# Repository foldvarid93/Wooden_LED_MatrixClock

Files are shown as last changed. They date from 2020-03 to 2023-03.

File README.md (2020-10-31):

# Wooden LED module matrix clock 

22829030_1608415815887806_506846079193605210_o






2020-10-31_08h34_10

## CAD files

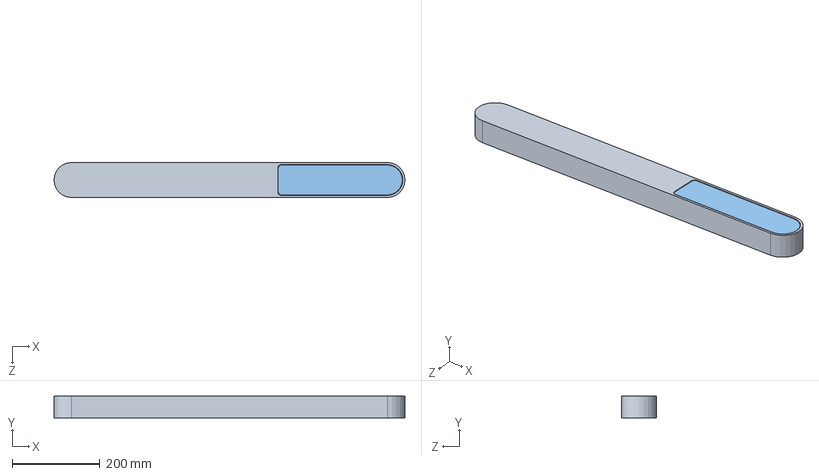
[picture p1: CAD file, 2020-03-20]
04_CAD_CAM/01_CAD/assembly.SLDASM
800.0 x 50.0 x 80.0 mm
flipclock
MAX7219_8X8LED_BOARD x 12

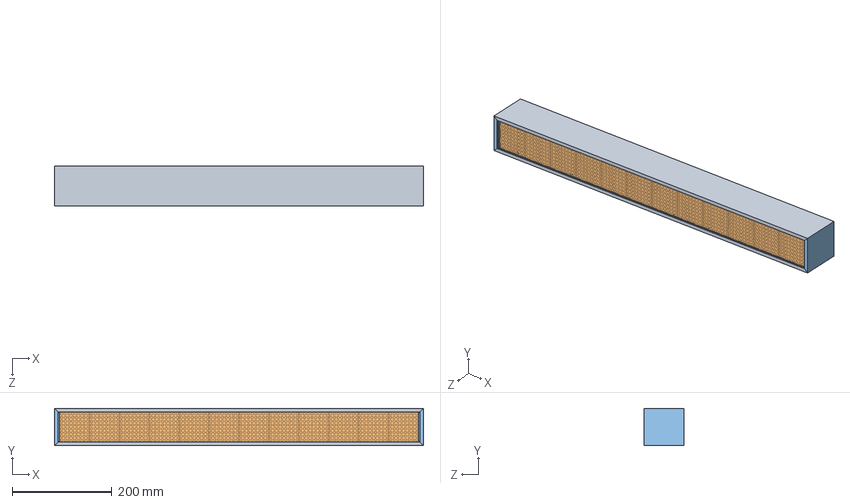
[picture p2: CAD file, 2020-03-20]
04_CAD_CAM/01_CAD/v2/assembly.SLDASM
740.5 x 74.5 x 80.0 mm
hosszu x 2
MAX7219_8X8LED_BOARD x 12
vegek2 x 2

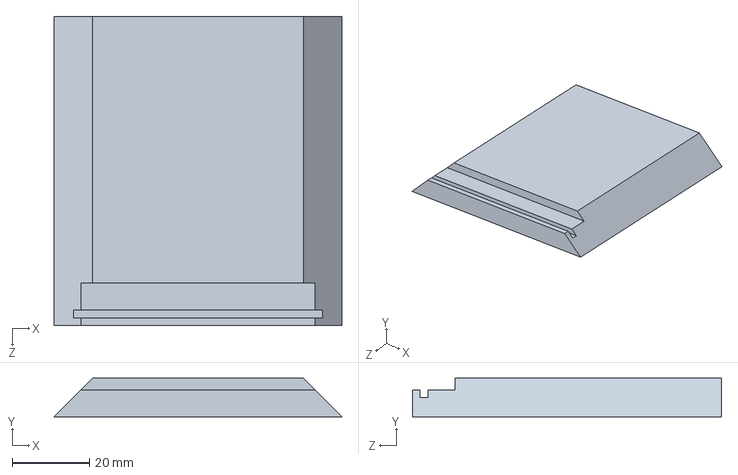
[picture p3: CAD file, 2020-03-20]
04_CAD_CAM/01_CAD/v2/vegek2.SLDPRT
74.5 x 10.0 x 80.0 mm

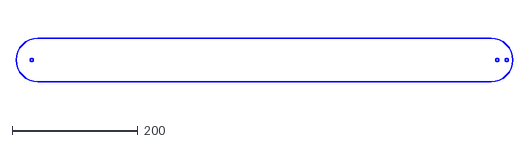
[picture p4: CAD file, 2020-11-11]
04_CAD_CAM/02_CAM/01_Aspire/glass.dxf
789.0 x 69.0

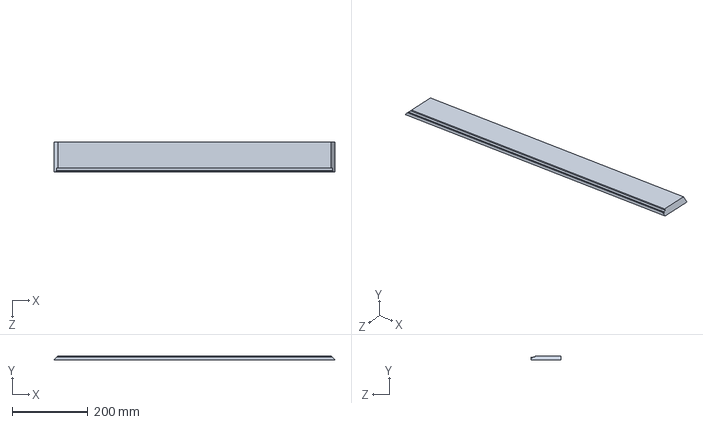
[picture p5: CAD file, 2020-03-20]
04_CAD_CAM/01_CAD/v2/hosszu.SLDPRT
740.5 x 10.0 x 80.0 mm

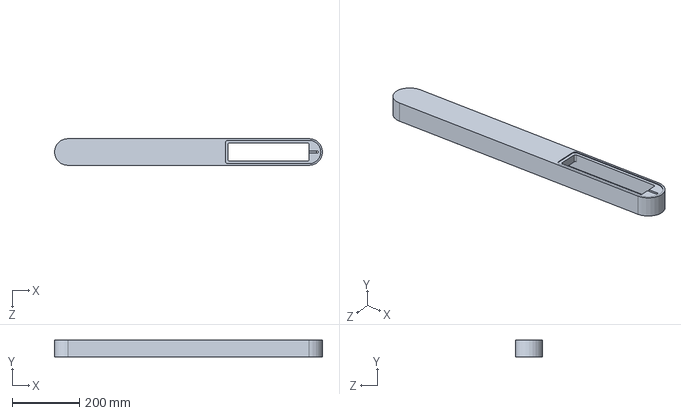
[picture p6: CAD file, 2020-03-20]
04_CAD_CAM/01_CAD/flipclock.SLDPRT
800.0 x 50.0 x 80.0 mm

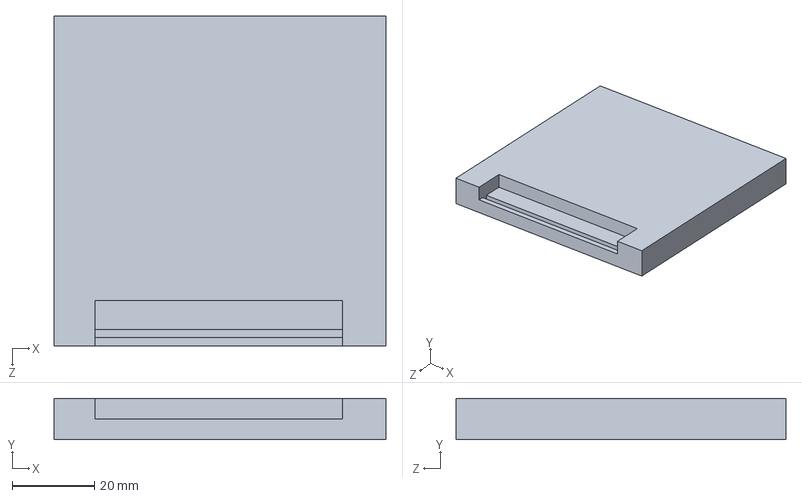
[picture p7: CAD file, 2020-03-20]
04_CAD_CAM/01_CAD/v2/vegek.SLDPRT
80.5 x 10.0 x 80.0 mm

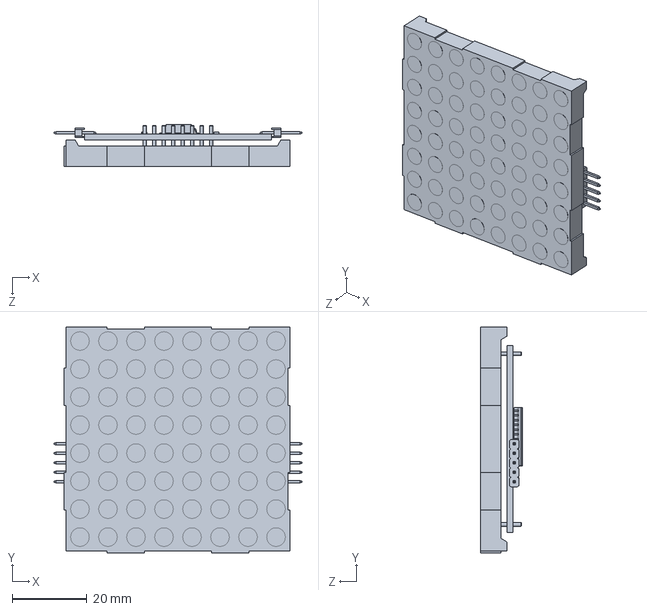
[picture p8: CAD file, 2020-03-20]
04_CAD_CAM/01_CAD/MAX7219_8X8LED_BOARD.SLDPRT
66.4 x 60.5 x 11.3 mm

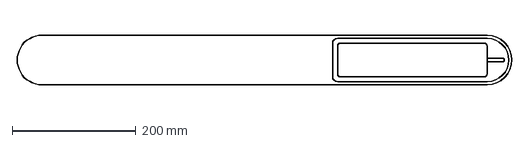
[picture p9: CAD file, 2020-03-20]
04_CAD_CAM/01_CAD/flipclock_b.DXF
801.8 x 80.0 mm

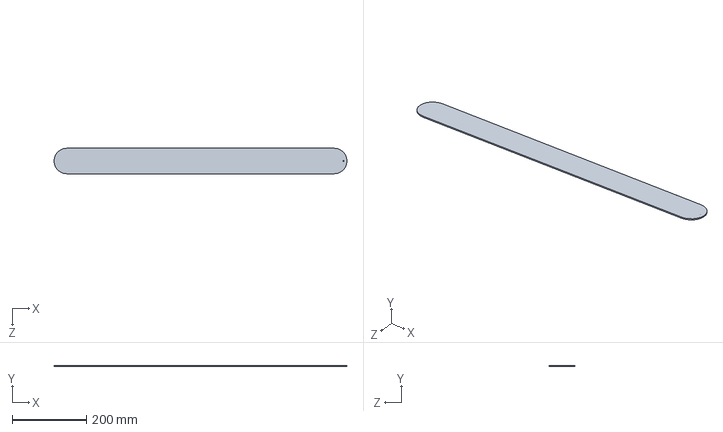
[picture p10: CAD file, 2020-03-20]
04_CAD_CAM/01_CAD/plexi.SLDPRT
789.0 x 3.00 x 69.0 mm

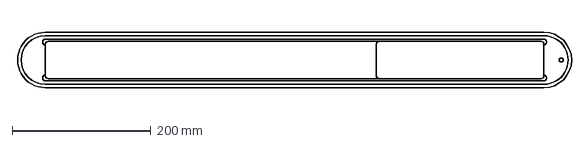
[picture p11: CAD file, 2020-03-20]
04_CAD_CAM/01_CAD/flipclock_f.DXF
801.8 x 80.0 mm

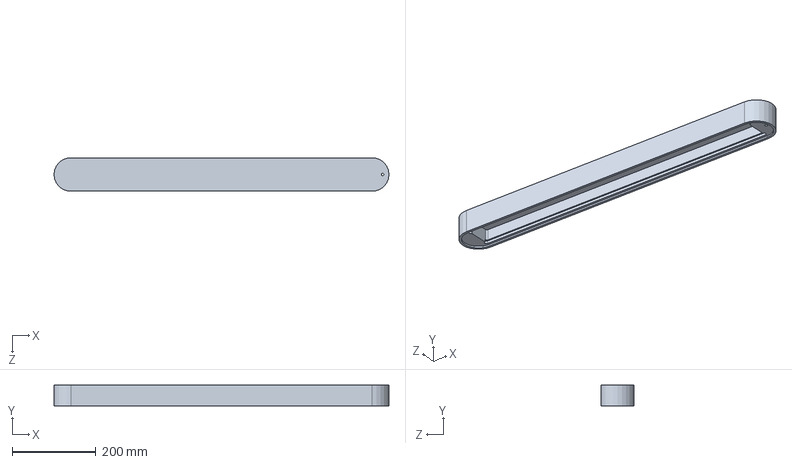
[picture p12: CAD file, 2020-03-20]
04_CAD_CAM/01_CAD/flipclock1.SLDPRT
800.0 x 50.0 x 80.0 mm

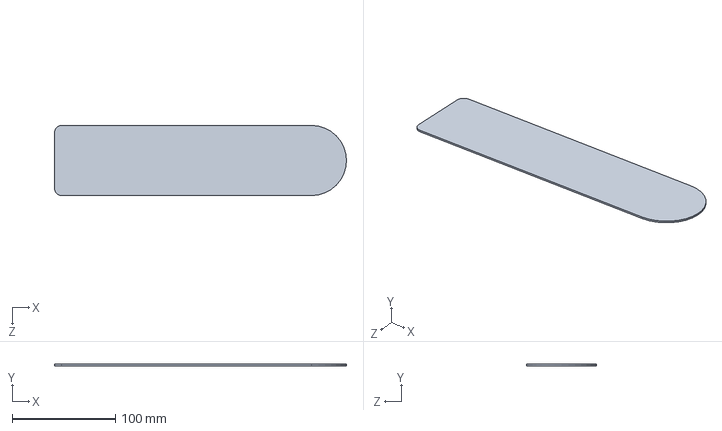
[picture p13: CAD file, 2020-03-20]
04_CAD_CAM/01_CAD/hatsotakaro.SLDPRT
283.0 x 1.50 x 68.0 mm

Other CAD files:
04_CAD_CAM/01_CAD/FlipClockAssembly.SLDASM
04_CAD_CAM/01_CAD/Assem5.SLDASM
04_CAD_CAM/01_CAD/flipclock.DXF
04_CAD_CAM/01_CAD/flipclock.SLDDRW
04_CAD_CAM/02_CAM/01_Aspire/Glass.SLDDRW

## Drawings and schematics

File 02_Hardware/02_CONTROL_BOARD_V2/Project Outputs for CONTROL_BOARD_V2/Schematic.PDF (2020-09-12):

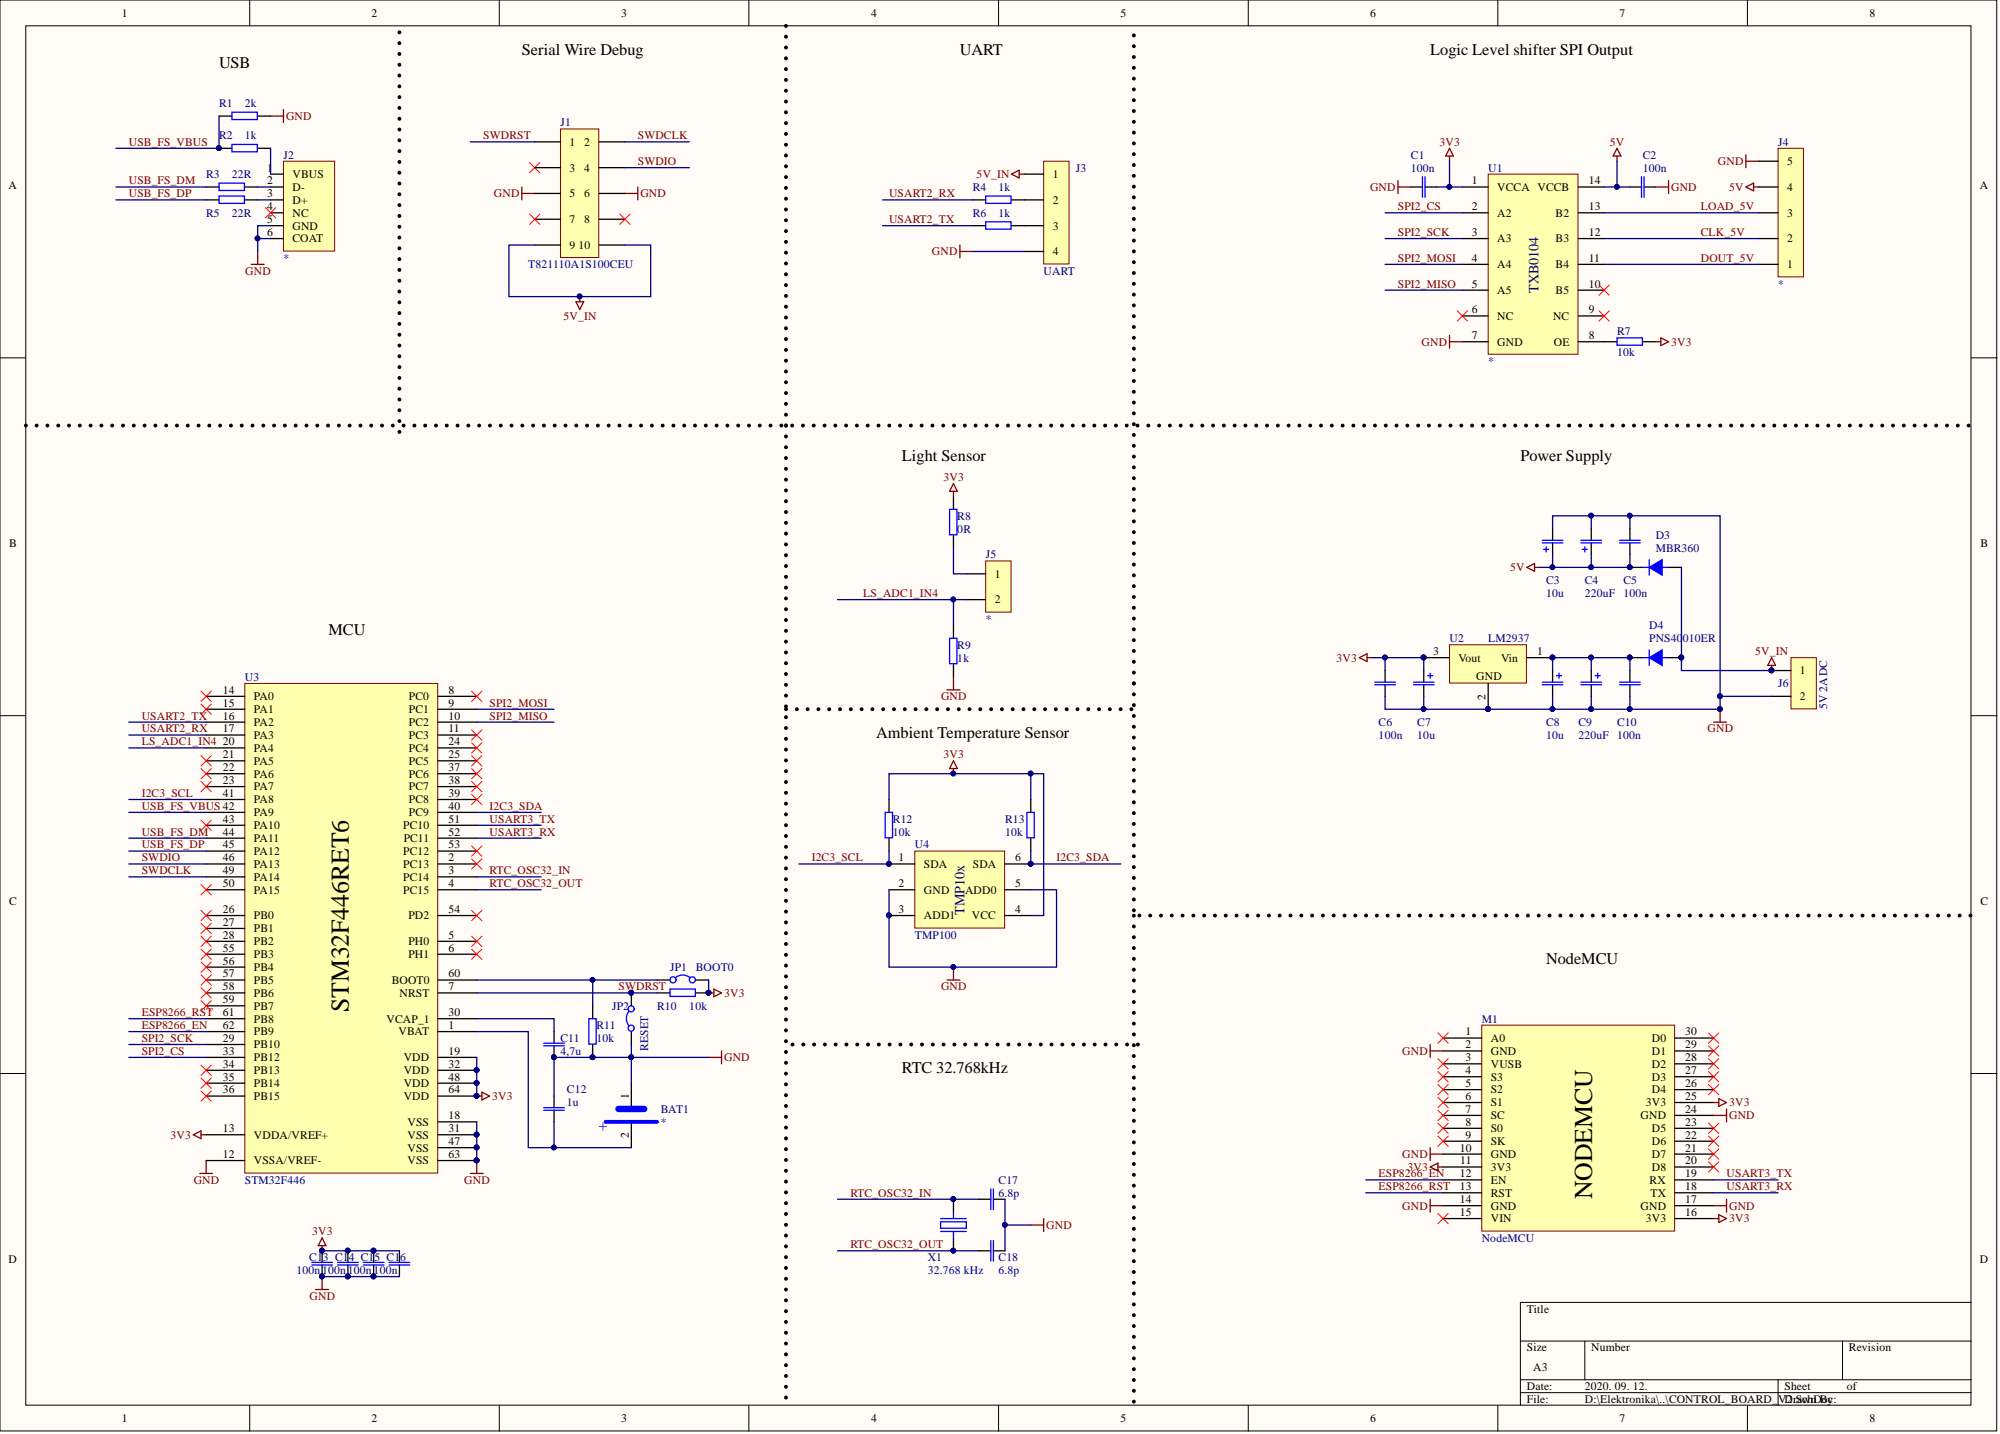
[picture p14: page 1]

Logic Level shifter SPI Output

VDDA/VREF+ 13 | 1u

Designator | Quantity | Name | Value | Description | Distributor | Reference ID | Comment
BAT1 | 1 | | | battery
C1, C2, C5, C6, C10, C | 9 | | 100n | NON POLARIZED CAPACITOR | | | 100n
C3, C7, C8 | 3 | | 10u | POLARIZEDCAPACITOR | | | 10u
C4, C9 | 2 | | 220uF | POLARIZEDCAPACITOR | | | 220uF
C11 | 1 | | 4,7u | NON POLARIZED CAPACITOR | | | 4,7u
C12 | 1 | | 1u | NON POLARIZED CAPACITOR | | | 1u
C17, C18 | 2 | | 6.8p | NON POLARIZED CAPACITOR | | | 6.8p
D3 | 1 | MBR360 | MBR360 | ON SemiconductorMBR360,SCHOTTKY | | | MBR360
D4 | 1 | PNS40010ER | PNS40010ER,115 | Nexperia PNS40010ER,115 switching diode 1.4RS Components | | 136-4874 | PNS40010ER
J1 | 1 | T821 | T821110A1S100CET821, 10pin, 2x5 connector, 2.54mm | | RS Components | 832-3528 | T821110A1S100CEU
J2 | 1 | | | 5PIN miniUSB SMD connector | LOMEX | 43-28-33
J3 | 1 | | UART | 4 PIN HEADER | | | UART
J4 | 1 | | | 5 PIN HEADER
J5 | 1 | | | 2 PIN HEADER
J6 | 1 | 5V 2A DC | 282837-2 | 2 Pin Terminal Block | RS Components | 710-0100 | 5V 2A DC
JP1 | 1 | BOOT0 | | JUMPER | | | BOOT0
JP2 | 1 | RESET | | JUMPER | | | RESET
M1 | 1 | NodeMCU | | Node MCU ESP12 module | | | NodeMCU
R1 | 1 | | 2k | RESISTOR | | | 2k
R2, R4, R6, R9 | 4 | | 1k | RESISTOR | | | 1k
R3, R5 | 2 | | 22R | RESISTOR | | | 22R
R7, R10, R11, R12, R1 | 5 | | 10k | RESISTOR | | | 10k
R8 | 1 | | 0R | RESISTOR | | | 0R
U1 | 1 | | | Voltage level shifter
U2 | 1 | LM2937 | LM2937IMP-3.3/NOLDO-regulator 400mA 3,3 V 5%, 4,75 → 26 V,RSComponents | | | 761-5599 | LM2937
U3 | 1 | STM32F446 | STM32F446RET6 | MCU STM32F446RET6 32bit, ARM Cortex M4, 1RSComp onents | | 110-6621 | STM32F446
U4 | 1 | TMP100 | TMP100 | Temperature sensor with I2C interface | | | TMP100
X1 | 1 | X32K768L104 | 32.768 kHz | Crystal, 32.768 kHz, Cylinder Radial, 8mm x 3mm Farnell | | 9509682 | 32.768 kHz

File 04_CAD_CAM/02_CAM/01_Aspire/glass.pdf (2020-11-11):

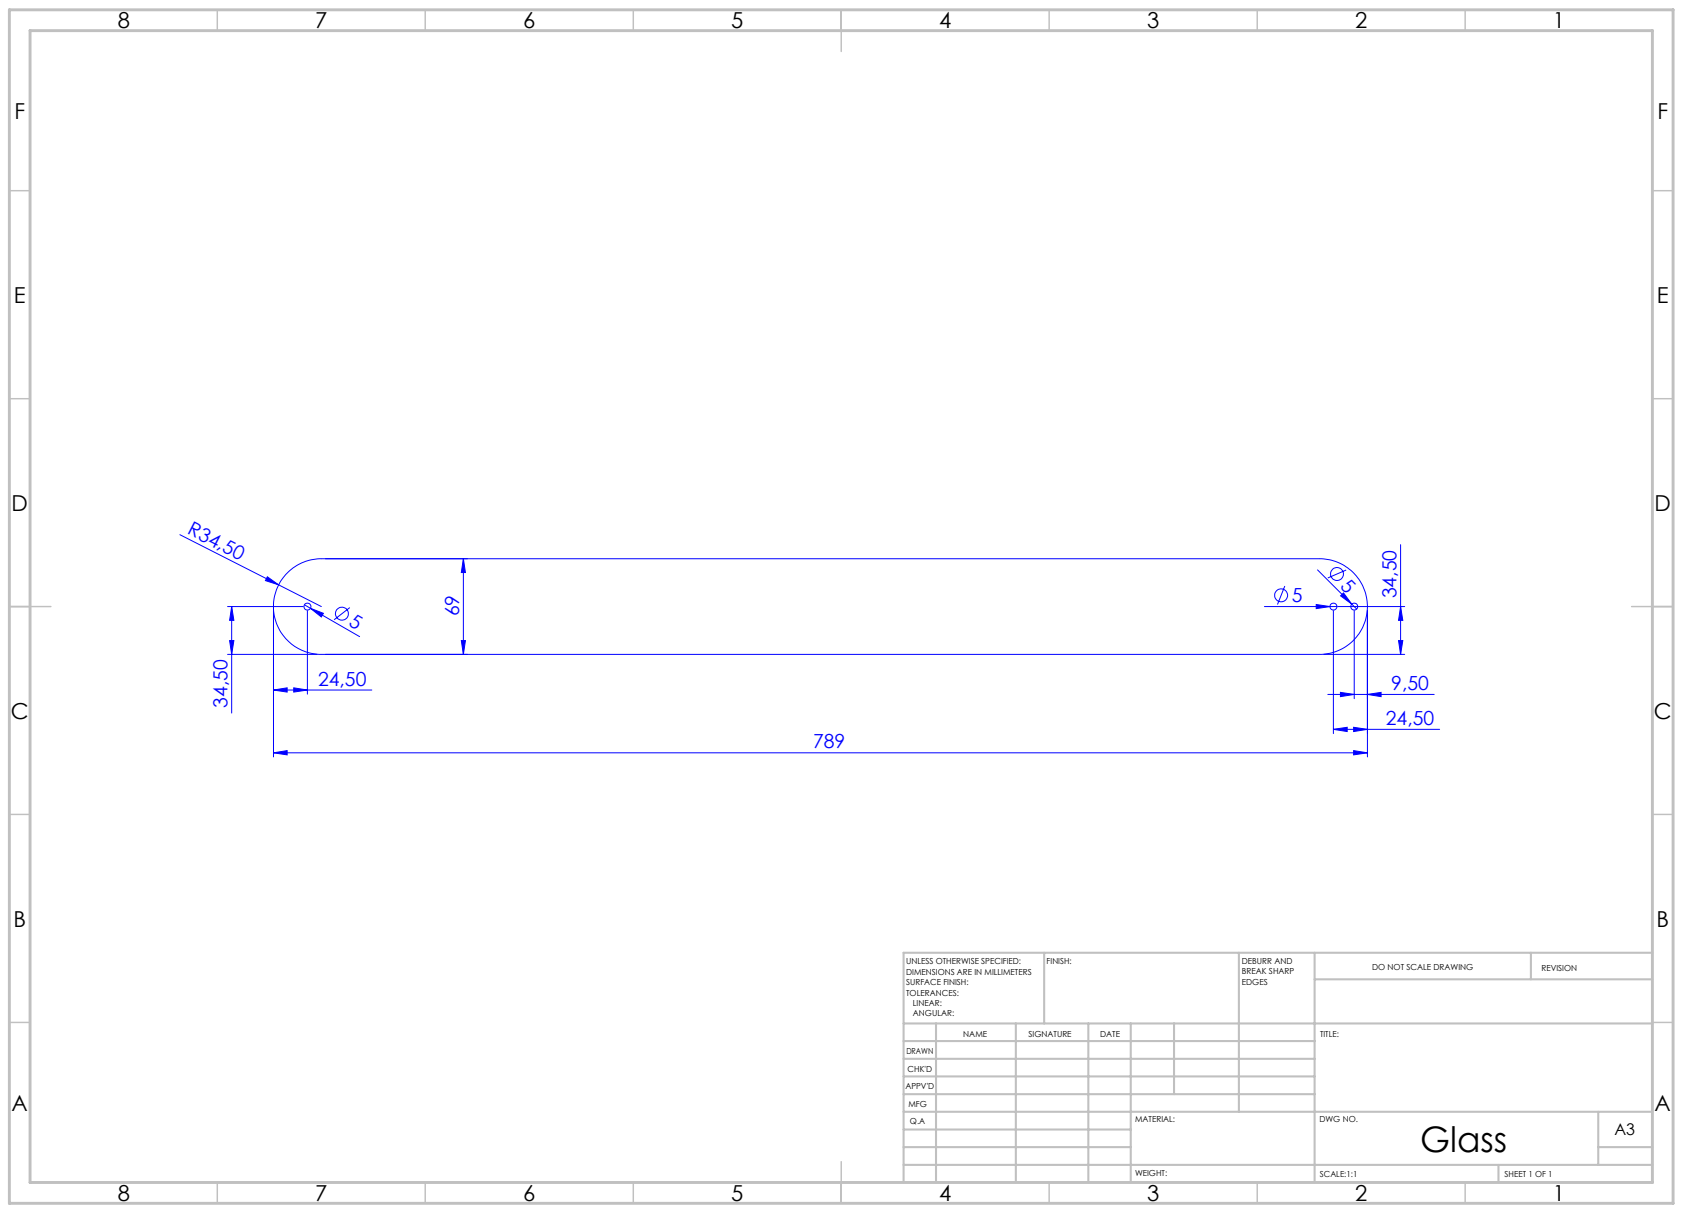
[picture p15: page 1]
FINISH:; DEBURR AND; BREAK SHARP; DO NOT SCALE DRAWING; REVISION; SCALE:1:1; SHEET 1 OF 1

UNLESS OTHERWISE SPECIFIED:
DIMENSIONS ARE IN MILLIMETERS
SURFACE FINISH:
TOLERANCES:
LINEAR:
ANGULAR:

NAME | SIGNATURE | DATE | | | | TITLE:

DRAWN
CHK'D
APPV'D
MFG
Q.A | | | | MATERIAL: | DWG NO. Glass | A3

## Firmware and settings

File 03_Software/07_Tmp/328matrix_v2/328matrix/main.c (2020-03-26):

#define F_CPU 16000000U
#include <util/delay.h>
#include <util/twi.h>
#include <stdlib.h>
#include <stdio.h>
#include <string.h>
#include <avr/interrupt.h>
#include "characters.h"
#include "bitfields.h"
/*********************************///
#pragma GCC diagnostic ignored "-Wchar-subscripts"
#pragma GCC diagnostic ignored "-Wunused-value"
#pragma GCC diagnostic ignored "-Wunused-variable"
/*********************************///
#define		SDAT		portb.bit.b0
#define		SCLK		portb.bit.b1
#define		STROBE		portb.bit.b2
#define		ODAT		portb.bit.b3
#define		OCLK		portb.bit.b4
/*********************************///
//#define		SET			portb.bit.b3
//#define		INCR		portb.bit.b1
//#define		DECR		portb.bit.b2
#define		RTC_ADDR	0xD0
#define		SEC_REG		0x00
/*********************************///
typedef struct RTC_DATA{
	unsigned char	sec;
	unsigned char	min;
	unsigned char	hour;
	unsigned char	day;
	unsigned char	date;
	unsigned char	month;
	unsigned char	year;
}RTC_DATA;
typedef struct TIME{
	unsigned char hour_tens;
	unsigned char hour_singles;
	unsigned char min_tens;
	unsigned char min_singles;
	unsigned char sec_tens;
	unsigned char sec_singles;
}TIME;
typedef struct DATE{
	unsigned char day;
	unsigned char date_tens;
	unsigned char date_singles;
	unsigned char month_tens;
	unsigned char month_singles;
	const char year_thousands;
	const char year_hundreds;
	unsigned char year_tens;
	unsigned char year_singles;
}DATE;
struct {
	unsigned char TIME_SET : 1;
	unsigned char DATE_TIME :1;
} MASK;
struct {
	unsigned char B0 :1;
	unsigned char B1 :1;
	unsigned char B2 :1;
	unsigned char B3 :1;
	unsigned char B4 :1;
	unsigned char B5 :1;
	unsigned char B6 :1;
	unsigned char B7 :1;
} MASKBYTE;
/*********************************///
unsigned char minutes=0;
unsigned char IT=0, PRESS_LENGTH=0,TIMER_LENGTH=0;
unsigned char data[48];
unsigned char datatmp[256];
RTC_DATA	rtcdata;//={0,0,0,6,2,8,15};//sec,min,hour,day,date,month,year
TIME	 	time[2] ={{0,0,0,0,0,0},{0,0,0,0,0,0}};
DATE		date={0,0,0,0,0,2,0,0,0};
const unsigned char	PROGMEM szoveg[] ={"A mai dátum: "};
const unsigned char PROGMEM	weekdays[7][10]={{"hétfõ"},{"kedd"},{"szerda"},{"csütörtök"},{"péntek"},{"szombat"},{"vasárnap"}};
const unsigned char	PROGMEM months[12][12]={{"január"},{"február"},{"március"},{"április"},{"május"},{"június"},{"július"},
{"augusztus"},{"szeptember"},{"október"},{"november"},{"december"}};
/*********************************///
void fill_datatmp(char adat,char kezd){
	for(char i=0;i<6;i++){datatmp[kezd+i]=pgm_read_byte(&(characters[adat][i]));}
}
void copy(char target_from, char target_to, char source_from){
	for(char i=target_from;i<target_to;i++){
		data[i]=datatmp[i+source_from];
	}
}
void fill_display(TIME* time,char kezd){
	fill_datatmp(time->hour_tens+'0',kezd+0);
	fill_datatmp(time->hour_singles+'0',kezd+6);
	fill_datatmp(':',60);	
	fill_datatmp(time->min_tens+'0',kezd+18);
	fill_datatmp(time->min_singles+'0',kezd+24);
	fill_datatmp(':',78);		
	fill_datatmp(time->sec_tens+'0',kezd+36);
	fill_datatmp(time->sec_singles+'0',kezd+42);
}
void shift(const char a){
	STROBE=0;
	for(char i=0;i<6;i++){
		int tmp=data[((5-i)*8)+a];
		for(char j=0;j<8;j++){
			if (tmp &0x80){// 0x01){
				SDAT=0;//SDAT=1;
			}
			else SDAT=1;//SDAT=0
			SCLK=1;
			SCLK=0;
			tmp<<=1;
		}
	}
	for(int i=0;i<6;i++){
		for(char j=8;j>=1;j--){
			if(j==a+1){ODAT=1;}
			else ODAT=0;
			OCLK=1;
			OCLK=0;
		}
	}
	STROBE=1;
}
void clear(char from, char to){
	for(char i=from;i<to;i++){
		data[i]=0xFF;
	}
}
/*********************************///I2C functions
void TWIStart(void){
	TWCR = (1<<TWINT)|(1<<TWSTA)|(1<<TWEN);
	while ((TWCR & (1<<TWINT)) == 0);
}
void TWIStop(void){
	TWCR = (1<<TWINT)|(1<<TWSTO)|(1<<TWEN);
}
void TWIWrite(uint8_t u8data){
	TWDR = u8data;
	TWCR = (1<<TWINT)|(1<<TWEN);
	while ((TWCR & (1<<TWINT)) == 0);
}
char TWIReadACK(void){
	TWCR = (1<<TWINT)|(1<<TWEN)|(1<<TWEA);
	while ((TWCR & (1<<TWINT)) == 0);
	return TWDR;
}
char TWIReadNACK(void){
	TWCR = (1<<TWINT)|(1<<TWEN);
	while ((TWCR & (1<<TWINT)) == 0);
	return TWDR;
}
char TWIGetStatus(void){
	uint8_t status;
	//mask status
	status = TWSR & 0xF8;
	return status;
}
/*********************************///
char atalakit(char tmp){
	char tizes=0;
	while(tmp>=10){
		tizes++;
		tmp-=10;
	}
	tizes<<=4;
	tizes&0x70;
	tmp&=0x0F;
	return(tizes|tmp);
}
void felbont(unsigned char tmp, unsigned char* ten, unsigned char* single){
	*single=(tmp&0x0F);
	tmp>>=4;
	*ten=(tmp&0x07);
}
/*********************************///RTC functions
unsigned char readrtcreg(unsigned char ADDR){
	unsigned char data;
	TWIStart();
	TWIWrite(RTC_ADDR);
	TWIWrite(ADDR);
	TWIStart();
	TWIWrite(RTC_ADDR+0x01);
	data=TWIReadNACK();
	TWIStop();
	return data;
}
void rtcread_time(TIME* time){
/*
	TWIStart();
	TWIWrite(RTC_ADDR);
	TWIWrite(SEC_REG);
	TWIStart();
	TWIWrite(RTC_ADDR+0x01);
	rtcdata.sec=TWIReadACK();
	rtcdata.min=TWIReadACK();
	rtcdata.hour=TWIReadNACK();
	TWIStop();*/
	rtcdata.sec=readrtcreg(0x00);
	rtcdata.min=readrtcreg(0x01);
	rtcdata.hour=readrtcreg(0x02);	
	felbont(rtcdata.hour,&time->hour_tens,&time->hour_singles);
	felbont(rtcdata.min,&time->min_tens,&time->min_singles);
	felbont(rtcdata.sec,&time->sec_tens,&time->sec_singles);
}
void rtcread_date(DATE* date){
/*
	TWIStart();
	TWIWrite(RTC_ADDR);
	TWIWrite(SEC_REG+3);
	TWIStart();
	TWIWrite(RTC_ADDR+0x01);	
	rtcdata.day=TWIReadACK();
	rtcdata.date=TWIReadACK();
	rtcdata.month=TWIReadACK();
	rtcdata.year=TWIReadNACK();
	TWIStop();*/
	rtcdata.day=readrtcreg(0x03);
	rtcdata.date=readrtcreg(0x04);
	rtcdata.month=readrtcreg(0x05);
	rtcdata.year=readrtcreg(0x06);
	date->day=rtcdata.day;
	felbont(rtcdata.date,&date->date_tens,&date->date_singles);
	felbont(rtcdata.month,&date->month_tens,&date->month_singles);
	felbont(rtcdata.year,&date->year_tens,&date->year_singles);	
}
void rtcread(TIME* time, DATE* date){
	rtcread_time(time);
	rtcread_date(date);
}
void rtcwritetime(void){
	TWIStart();
	TWIWrite(RTC_ADDR);
	TWIWrite(SEC_REG);
	TWIWrite(0);
	TWIWrite(atalakit(12));
	TWIWrite(atalakit(9));
	TWIStop();	
}
void rtcwritedate(void){
	TWIStart();
	TWIWrite(RTC_ADDR);
	TWIWrite(SEC_REG+3);
	TWIWrite(2);
	TWIWrite(atalakit(23));
	TWIWrite(atalakit(12));
	TWIWrite(atalakit(15));
	TWIStop();	
}
void first_read(){
	rtcread(&time[1],&date);
	fill_display(&time[1],48);
	copy(0,48,48);
}
/*********************************///Text functions
void text_out(const unsigned char *text){
	unsigned char length=0, temp, i=0,kar_elt=0,b=8;	//length=strlength(text);
	while(text[length]!='\0'){length++;}
	if(length<8){b=length;}
	for(char j=0;j<b;j++){
		temp=text[j];
		for(char k=0;k<6;k++,i++){
			data[i]=pgm_read_byte(&(characters[temp][k]));
		}
	}
	if(length<=8){
		for(;i<48;i++){data[i]=0xff;}
		_delay_ms(3000);
		return;
	}
	for(kar_elt=8;kar_elt<length;kar_elt++){
		temp=text[kar_elt];
		for(char j=0;j<6;j++){
			for(char l=0;l<47;l++){data[l]=data[l+1];}
			data[47]=pgm_read_byte(&(characters[temp][j]));
			_delay_ms(70);
		}
	}
	return;
}
void const_text_out(const unsigned char* text){
	for(unsigned char i=0;pgm_read_byte(&text[i])!='\0'&&i<0xFF;i++){datatmp[i]=pgm_read_byte(&text[i]);}
	text_out(datatmp);
}
/*********************************///Time functions
char concat(char b, char a){
	a>>=1;
	if(b&0x01){a|=0x80;}
	else{a&=0x7F;}
	return a;
}
void time_out(void){
	MASKBYTE.B0=MASKBYTE.B1=MASKBYTE.B2=MASKBYTE.B3=MASKBYTE.B4=MASKBYTE.B5=0;
	rtcread_time(&time[0]);
	fill_display(&time[0],0);	
	
	if (time[0].sec_singles!=time[1].sec_singles) MASKBYTE.B0=1;
	if (time[0].sec_tens!=time[1].sec_tens) MASKBYTE.B1=1;
	if (time[0].min_singles!=time[1].min_singles) MASKBYTE.B2=1;
	if (time[0].min_tens!=time[1].min_tens) MASKBYTE.B3=1;
	if (time[0].hour_singles!=time[1].hour_singles) MASKBYTE.B4=1;
	if (time[0].hour_tens!=time[1].hour_tens) MASKBYTE.B5=1;
	
	if(!MASKBYTE.B0&&!MASKBYTE.B1&&!MASKBYTE.B2&&!MASKBYTE.B3&&!MASKBYTE.B4&&!MASKBYTE.B5){
		//ez helyett vagy kéne 
	}
	else{
		for(int j=0;j<8;j++){
			if(MASKBYTE.B0){for(char i=0;i<6;i++){datatmp[90+i]=concat(datatmp[42+i],datatmp[90+i]);}}
			if(MASKBYTE.B1){for(char i=0;i<6;i++){datatmp[84+i]=concat(datatmp[36+i],datatmp[84+i]);}}
			if(MASKBYTE.B2){for(char i=0;i<6;i++){datatmp[72+i]=concat(datatmp[24+i],datatmp[72+i]);}}
			if(MASKBYTE.B3){for(char i=0;i<6;i++){datatmp[66+i]=concat(datatmp[18+i],datatmp[66+i]);}}
			if(MASKBYTE.B4){for(char i=0;i<6;i++){datatmp[54+i]=concat(datatmp[6+i],datatmp[54+i]);}}
			if(MASKBYTE.B5){for(char i=0;i<6;i++){datatmp[48+i]=concat(datatmp[i],datatmp[48+i]);}}
			for(char i=0;i<48;i++){datatmp[i]>>=1;}
			copy(0,48,48);
			_delay_ms(35);
		}
	}
	time[1]=time[0];
}
void set_time(void){
	time[0].hour_tens=minutes/60;
	time[0].min_tens=minutes%60;
	time[0].hour_singles=(time[0].hour_tens%10)+'0';
	time[0].hour_tens=(time[0].hour_tens/10)+'0';
	time[0].min_singles=(time[0].min_tens%10)+'0';
	time[0].min_tens=(time[0].min_tens/10)+'0';
	
	for(char i=0;i<48;i++){
		if (i==9)i=36;
		datatmp[i]=0xFF;
	}
	fill_datatmp(time[0].hour_tens,9);
	fill_datatmp(time[0].hour_singles,15);
	fill_datatmp(':',21);
	fill_datatmp(time[0].min_tens,27);
	fill_datatmp(time[0].min_singles,33);
	copy(0,48,0);
}
/*********************************///Date functions
void date_out(void){
	unsigned char i=0;
	rtcread_date(&date);
	for(i=0;i<8;i++){datatmp[i]=' ';}
	for(unsigned char j=0;pgm_read_byte(&szoveg[j])!='\0';i++,j++){datatmp[i]=pgm_read_byte(&szoveg[j]);}
	datatmp[i++]=date.year_thousands+'0';
	datatmp[i++]=date.year_hundreds+'0';
	datatmp[i++]=date.year_tens+'0';
	datatmp[i++]=date.year_singles+'0';
	datatmp[i++]='.';
	datatmp[i++]=date.month_tens+'0';
	datatmp[i++]=date.month_singles+'0';
	datatmp[i++]='.';
	datatmp[i++]=date.date_tens+'0';
	datatmp[i++]=date.date_singles+'0';
	datatmp[i++]='.';
	for(char j=0;pgm_read_byte(&weekdays[date.day][j])!='\0';i++,j++){
		datatmp[i]=pgm_read_byte(&weekdays[date.day][j]);
	}
	for(char j=0;j<8;i++,j++){datatmp[i]=' ';}
	datatmp[i]='\0';
	text_out(datatmp);
}
/*********************************///
void TWIInit(void){	//set SCL to 400kHz
	TWSR = 0x00;
	TWBR = 0x0C;
	TWCR = (1<<TWEN);	//enable TWI
}
void init_avr(void){
	DDRB=0xFF;
	DDRC=0xFF;
	DDRD=0b11111011;	//DDRD &= ~(1 << DDD2);     // Clear the PD2 pin	// PD2 (PCINT0 pin) is now an input
	PORTD |= (1 << PORTD2);    // turn On the Pull-up	// PD2 is now an input with pull-up enabled
	EICRA |= (1 << ISC01);    // set INT0 to trigger on ANY logic change
	EIMSK |= (1 << INT0);     // Turns on INT0
}	
void Init_Timer0(void){
	TCCR0A|=0B00000010;//setWGM01
	TCCR0A&=0B11111110;//clearWGM00
	TCCR0B|=0B00000011;//setCS01
	TCCR0B&=0B11110011;//clearWGM02, clearCS00, clear CS02		
	TIMSK0 |= (1 << TOIE0);
	OCR0A=0xFF;
}
void Init_Timer1(void){
    OCR1A = 15624;
    TCCR1B |= (1 << WGM12);
    TIMSK1 |= (1 << OCIE1A);
    TCCR1B |= (1 << CS12) | (1 << CS10);
}
/*********************************///
void main(void){
	init_avr();	
	Init_Timer0();
	sei();
	TWIInit();
	//TWIStart();
	//TWIWrite(RTC_ADDR);
	//TWIWrite(SEC_REG+7);
	//TWIWrite(0x10);
	//TWIStop();	
	//rtcwritetime();
	//rtcwritedate();
	first_read();
    while (1){
		//const_text_out(szoveg);
		//date_out();
		time_out();
		_delay_ms(25);
	}
}
/*********************************///
ISR (TIMER0_OVF_vect){
	if (IT==8){	IT=0;}
	shift(IT);
	IT++;
}
ISR (TIMER1_COMPA_vect){
	///spi kiszolgálás 
}
ISR (INT0_vect){
	portb.bit.b5=~portb.bit.b5;
}
/*********************************///
//void interrupt TIMER_ISR(void) {
	//if (PIR1bits.TMR1IF==1){
		//if(SET&&!MASK.TIME_SET){
			//TIMER_LENGTH++;
			//if(TIMER_LENGTH==100){
				//MASK.DATE_TIME=1;
				//TIMER_LENGTH=0;
			//}
		//}
		//if(!SET&&!MASK.TIME_SET){
			//MASK.TIME_SET=1;
			//TIMER_LENGTH=50;
			//rtcread(&time[0],&date);
			//minutes=time[0].min_singles+time[0].min_tens*10+((time[0].hour_singles+time[0].hour_tens*10)*60);
		//}
		//if(TIMER_LENGTH>0&&MASK.TIME_SET){
			//if (INCR == 1 & DECR == 1) {
				//PRESS_LENGTH = 0;
				//TIMER_LENGTH--;
				//if(TIMER_LENGTH==0){
					//MASK.TIME_SET=0;
					//rtcwrite_time(minutes);
				//}
			//}
			////----------------------------------------------------------------------------////NÖVELÉS
			//if (INCR == 0) {
				//if (PRESS_LENGTH <= 10) {minutes++;PRESS_LENGTH++;}
				//if (PRESS_LENGTH<30&&PRESS_LENGTH>10) {minutes += 10;PRESS_LENGTH++;}
				//if (PRESS_LENGTH >= 30) {minutes += 60;}
				//if (minutes>1439){minutes-=1440;}
			//}
			////----------------------------------------------------------------------------////CSÖKKENTÉS
			//if (DECR == 0) {
				//if (PRESS_LENGTH <= 10) {minutes--;PRESS_LENGTH++;}
				//if (PRESS_LENGTH > 10&&PRESS_LENGTH<30) {minutes-=10;PRESS_LENGTH++;}
				//if (PRESS_LENGTH >= 30) {minutes -= 60;}
				//if (minutes<0){minutes+=1440;}
			//}
		//}
		//TMR1L=0x00;
		//TMR1H=0x00;
		//PIR1bits.TMR1IF=0;
	//}
//}
		//for(char j=0;j<9;j++){
			//temp=pgm_read_byte(&(text[j]));	
			//for(char k=0;k<6;k++){
				//data[i]=pgm_read_byte(&(characters[temp][k]));		//			data[i]=characters[((*(text+j))*6)+k];
				//i++;
			//}						
		//}
		//
		//
		//while(1){
			//i=0;
			//if((length-kar_elt)==8){break;}//vége 
			//if(betu_elt!=0){
				//i=0;
				//temp=pgm_read_byte(&(text[kar_elt]));
				//for(char j=0;j<(6-betu_elt);j++,i++){
					//data[i]=pgm_read_byte(&(characters[temp][j]));
				//}
			//}
			//b=kar_elt;
			//if(betu_elt!=0){
				//b++;
			//}
			//while(i<48){
				//for(char j=0;j<6;j++,i++){
					//data[i]=pgm_read_byte(&(characters[(text+b)][j]));
				//}
				//b++;
			//}
			//betu_elt++;
			//if(betu_elt==6){
				//betu_elt=0;
				//kar_elt++;
			//}
			//_delay_ms(15);
		//}
	//}
		//for(;kar_elt+8<=length;kar_elt++){
		//i=0;
		//for(char j=0;j<8;j++){
			//temp=pgm_read_byte(&(text[kar_elt+j]));
			//for(char k=0;k<6;k++,i++){
				//data[i]=pgm_read_byte(&(characters[temp][k]));
			//}
		//}
	//}
		//if(length<9){
		//for(char j=0;j<length;j++){
			//temp=pgm_read_byte(&(text[j]));			
			//for(char k=0;k<6;k++,i++){
				//data[i]=pgm_read_byte(&(characters[temp][k]));		//			data[i]=characters[((*(text+j))*6)+k];
			//}
		//}
		//for(;i<48;i++){
			//data[i]=0xff;
		//}
		//_delay_ms(3000);
	//}
	//void text_out(const unsigned char* text){
		//unsigned char length, temp;
		//length=strlength(text);
		//for(char j=0; j<length;j++){
			//temp=pgm_read_byte(&(text[j]));
			//for(char i=0;i<6;i++){
				//data[(j*6)+i]=pgm_read_byte(&(characters[temp][i]));
			//}
		//}
	//}
//char strlength(const unsigned char* text){
	//unsigned char length=0;
	//while(pgm_read_byte(&text[length])!='\0'){
		//length++;
	//}
	//return length;
//}	
/**************************************************///inicializálások

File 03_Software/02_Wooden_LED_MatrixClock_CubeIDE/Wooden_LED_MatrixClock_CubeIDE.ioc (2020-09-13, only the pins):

Mcu.UserName=STM32F446RETx
PA13.GPIO_Label=SWDIO
PA13.Signal=SYS_JTMS-SWDIO
PA14.GPIO_Label=SWDCLK
PA14.Signal=SYS_JTCK-SWCLK
PA2.GPIO_Label=USART2_TX
PA2.Signal=USART2_TX
PA3.GPIO_Label=USART2_RX
PA3.Signal=USART2_RX
PA4.GPIO_Label=LS_ADC1_IN4
PA4.Signal=ADCx_IN4
PA8.Signal=I2C3_SCL
PB10.Signal=SPI2_SCK
PB12.GPIO_Label=SPI2_CS
PB12.Signal=GPIO_Output
PB8.GPIO_Label=ESP8266_RST
PB8.Signal=GPIO_Output
PB9.GPIO_Label=ESP8266_EN
PB9.Signal=GPIO_Output
PC1.Signal=SPI2_MOSI
PC10.Signal=USART3_TX
PC11.Signal=USART3_RX
PC14-OSC32_IN.Signal=RCC_OSC32_IN
PC15-OSC32_OUT.Signal=RCC_OSC32_OUT
PC2.Signal=SPI2_MISO
PC9.Signal=I2C3_SDA
PH0-OSC_IN.Signal=RCC_OSC_IN
PH1-OSC_OUT.Signal=RCC_OSC_OUT

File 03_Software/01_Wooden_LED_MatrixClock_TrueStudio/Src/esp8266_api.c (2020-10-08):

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

/* Includes ------------------------------------------------------------------*/
#include "main.h"
#include "string.h"
#include "stdlib.h"

UART_HandleTypeDef huart1;
UART_HandleTypeDef huart2;

/* USER CODE BEGIN PV */
#define DEBUG 1
#define AT_COMMAND_BUFFER_LENGTH 255
#define UART_RECEIVE_BUFFER_LENGTH 2048

uint8_t uartRxByte[1];
uint16_t i=0,j=0;
uint8_t *ptr;
uint8_t  c;
uint8_t AT_command[AT_COMMAND_BUFFER_LENGTH];
uint8_t uartReceive[UART_RECEIVE_BUFFER_LENGTH];
uint8_t uartReceiveEnd=0;
uint8_t HTTP_response[]="HTTP/1.1 200 OK\r\nContent-Type: text/html\r\nConnection: Closed\r\n\r\n\r\n";
HAL_StatusTypeDef res;
uint8_t handleData=0;
uint8_t HTTP_request_length_string[10];
uint16_t HTTP_request_length=0;
uint8_t HTTP_request_length_valid=0;

extern uint8_t webpage[1271];


/* USER CODE END PV */

void SystemClock_Config(void);
static void MX_GPIO_Init(void);
static void MX_USART1_UART_Init(void);
static void MX_USART2_UART_Init(void);
/**
  * @brief  The application entry point.
  * @retval int
  */
int main(void)
{
  /* USER CODE BEGIN 1 */
	InitWebpage();


  /* USER CODE END 1 */

  /* MCU Configuration--------------------------------------------------------*/

  /* Reset of all peripherals, Initializes the Flash interface and the Systick. */
  HAL_Init();

  /* Configure the system clock */
  SystemClock_Config();

  /* Initialize all configured peripherals */
  MX_GPIO_Init();
  MX_USART1_UART_Init();
  MX_USART2_UART_Init();
  /* USER CODE BEGIN 2 */
  	//HAL_UART_Receive_IT(&huart1, uartRxByte, 1);
	#ifdef DEBUG
		debugPrintf("\r\n");
		debugPrintf("\r\n");
		debugPrintf("######################\r\n");
		debugPrintf("######################\r\n");
		debugPrintf("######################\r\n");
	#endif

	//restore
	/*sprintf(AT_command,"%s","AT+RESTORE\r\n");
	HAL_UART_Transmit(&huart1,AT_command,strlen(AT_command),100);
	HAL_UART_Receive(&huart1,uartReceive,1024,100);
	//waitForUartResponse();
	//uartReceiveEnd=0;
	debugPrintf("ESP8266 restored to default\r\n");
	//debugPrintf(uartReceive);
	debugPrintf("-------------\r\n");*/

	//set uart parameters
	/*sprintf(AT_command,"%s","AT+UART_CUR=115200,8,1,0,0\r\n");
	HAL_UART_Transmit(&huart1,AT_command,strlen(AT_command),100);
	HAL_UART_Receive(&huart1,uartReceive,1024,100);
	//waitForUartResponse();
	//uartReceiveEnd=0;
	debugPrintf("ESP8266 uart parameters set\r\n");
	//debugPrintf(uartReceive);
	debugPrintf("-------------\r\n");*/

	//HAL_Delay(5000);

	//ATE0 switch off echo
	sprintf(AT_command,"%s","ATE0\r\n");
	HAL_UART_Transmit(&huart1,AT_command,strlen(AT_command),100);
	HAL_UART_Receive(&huart1,uartReceive,UART_RECEIVE_BUFFER_LENGTH,100);
	#ifdef DEBUG
		debugPrintf("ESP8266 echo switched off\r\n");
		//debugPrintf(uartReceive);
		debugPrintf("-------------\r\n");
	#endif


	//set wifi mode to Station mode (to be able to connect to a wifi router )
	sprintf(AT_command,"%s","AT+CWMODE_CUR=1\r\n");
	HAL_UART_Transmit(&huart1,AT_command,strlen(AT_command),100);
	HAL_UART_Receive(&huart1,uartReceive,UART_RECEIVE_BUFFER_LENGTH,100);
	#ifdef DEBUG
		debugPrintf("wifi mode set to Station mode: ");
		debugPrintf(uartReceive);
		debugPrintf("-------------\r\n");
	#endif

	//connect to a wifi network
	sprintf(AT_command,"%s%c%s%c%c%c%s%c%s","AT+CWJAP_CUR=",'"',"WIFI_network_name",'"',',','"',"WIFI_password",'"',"\r\n");  //replace WIFI_network_name and WIFI_password with your wifi network name and your password
	HAL_UART_Transmit(&huart1,AT_command,strlen(AT_command),100);
	debugPrintf("connecting to network...\r\n");
	HAL_UART_Receive(&huart1,uartReceive,UART_RECEIVE_BUFFER_LENGTH,10000); //give 10 seconds to connect to the wifi router
	#ifdef DEBUG
		debugPrintf(uartReceive);
		debugPrintf("-------------\r\n");
	#endif

	//get the mac address of ESP8266
	/*sprintf(AT_command,"%s","AT+CIPSTAMAC_CUR?\r\n");
	HAL_UART_Transmit(&huart1,AT_command,strlen(AT_command),100);
	HAL_UART_Receive(&huart1,uartReceive,255,100);
	debugPrintf("ESP8266 mac address: ");
	debugPrintf(uartReceive);
	debugPrintf("-------------\r\n");*/

	//get ip address of ESP8266
	sprintf(AT_command,"%s","AT+CIFSR\r\n");
	HAL_UART_Transmit(&huart1,AT_command,strlen(AT_command),100);
	HAL_UART_Receive(&huart1,uartReceive,UART_RECEIVE_BUFFER_LENGTH,100);
	#ifdef DEBUG
		debugPrintf("ESP8266 ip address: ");
		debugPrintf(uartReceive);
		debugPrintf("-------------\r\n");
	#endif

	//enable multiple connections
	sprintf(AT_command,"%s","AT+CIPMUX=1\r\n");
	HAL_UART_Transmit(&huart1,AT_command,strlen(AT_command),100);
	HAL_UART_Receive(&huart1,uartReceive,UART_RECEIVE_BUFFER_LENGTH,100);
	#ifdef DEBUG
		debugPrintf("single connection enabled: ");
		debugPrintf(uartReceive);
		debugPrintf("-------------\r\n");
	#endif

	//create server on port 80
	sprintf(AT_command,"%s","AT+CIPSERVER=1,80\r\n");
	HAL_UART_Transmit(&huart1,AT_command,strlen(AT_command),100);
	HAL_UART_Receive(&huart1,uartReceive,UART_RECEIVE_BUFFER_LENGTH,100);
	#ifdef DEBUG
		debugPrintf("Server started on port 80: ");
		debugPrintf(uartReceive);
		debugPrintf("-------------\r\n");
	#endif

	//start listening for HTTP requests
	HAL_UART_Receive_IT(&huart1, uartRxByte, 1);
  /* USER CODE END 2 */

  /* Infinite loop */
  /* USER CODE BEGIN WHILE */
  while (1)
  {
    /* USER CODE END WHILE */

    /* USER CODE BEGIN 3 */
	  /*HAL_GPIO_TogglePin(GPIOA,GPIO_PIN_5);
	  HAL_Delay(200);*/

	  if (handleData==1){
		  debugPrintf(uartReceive);
		  debugPrintf("\r\n");
		  debugPrintf("\r\nhandling received data\r\n");
		  HandleReceivedData();
		  handleData=0;
		  HAL_UART_Receive_IT(&huart1, uartRxByte, 1);
	  }

	 // HAL_Delay(100);
  }
  /* USER CODE END 3 */
}

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
/* USER CODE BEGIN 4 */

void HAL_UART_RxCpltCallback(UART_HandleTypeDef *UartHandle)
{
  /* Set transmission flag: transfer complete */
  //UartReady = SET;
	//HAL_GPIO_WritePin(LD2_GPIO_Port, LD2_Pin, GPIO_PIN_SET);


//	 -------------------------------------------------
//	 	 If the esp8266 gets a reuest on port 80 it will send the incoming TCP data to the microcontorller with a header:
//		example:
//
//		+IPD,0,321:GET / HTTP/1.1
//		Host: 192.168.1.104
//		User-Agent: Mozilla/5.0 (X11; Ubuntu; Linux x86_64; rv:66.0) Gecko/20100101 Firefox/66.0
//		Accept: text/html,application/xhtml+xml,application/xml;q=0.9,*/*;q=0.8
//		Accept-Language: en-US,en;q=0.5
//		Accept-Encoding: gzip, deflate
//		Connection: keep-alive
//		Upgrade-I..........
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

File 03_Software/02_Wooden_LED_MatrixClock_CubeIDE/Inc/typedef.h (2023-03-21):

/*
 * typedeff.h
 *
 *  Created on: 2020. okt. 21.
 *      Author: David
 */

#ifndef TYPEDEF_H_
#define TYPEDEF_H_
/**** INCLUDES ***********************************************************************************/
#include <stdbool.h>
#include <stdint.h>
/**** END OF INCLUDES ****************************************************************************/

/**** MACROS *************************************************************************************/
#define VA_NTP_SSID							(0x0)
#define SO_NTP_SSID							(50u)
	/**/
#define VA_NTP_PassWord 					(VA_NTP_SSID + SO_NTP_SSID)
#define SO_NTP_PassWord						(50u)
	/**/
#define VA_NTP_SyncEnabled 					(VA_NTP_PassWord + SO_NTP_PassWord)
#define SO_NTP_SyncEnabled					(2u)
	/**/
#define VA_NTP_SyncInterval 				(VA_NTP_SyncEnabled + SO_NTP_SyncEnabled)
#define SO_NTP_SyncInterval					(2u)
	/*Text*/
#define VA_Text_Message						(VA_NTP_SyncInterval + SO_NTP_SyncInterval)
#define SO_Text_Message						(256u)
	/**/
#define VA_Text_Enabled						(VA_Text_Message + SO_Text_Message)
#define SO_Text_Enabled						(2u)
	/**/
#define VA_Text_ScrollingMode				(VA_Text_Enabled + SO_Text_Enabled)
#define SO_Text_ScrollingMode				(2u)
	/**/
#define VA_Text_ScrollIntervalInSec			(VA_Text_ScrollingMode + SO_Text_ScrollingMode)
#define SO_Text_ScrollIntervalInSec			(2u)
	/*Date*/
#define VA_Date_Enabled						(VA_Text_ScrollIntervalInSec + SO_Text_ScrollIntervalInSec)
#define SO_Date_Enabled						(2u)
	/**/
#define VA_Date_ScrollingMode				(VA_Date_Enabled + SO_Date_Enabled)
#define SO_Date_ScrollingMode				(2u)
	/**/
#define VA_Date_ScrollIntervalInSec			(VA_Date_ScrollingMode + SO_Date_ScrollingMode)
#define SO_Date_ScrollIntervalInSec			(2u)
	/*Temp*/
#define VA_Temp_Enabled						(VA_Date_ScrollIntervalInSec + SO_Date_ScrollIntervalInSec)
#define SO_Temp_Enabled						(2u)
	/**/
#define VA_Temp_ScrollingMode				(VA_Temp_Enabled + SO_Temp_Enabled)
#define SO_Temp_ScrollingMode				(2u)
	/**/
#define VA_Temp_ScrollIntervalInSec			(VA_Temp_ScrollingMode + SO_Temp_ScrollingMode)
#define SO_Temp_ScrollIntervalInSec			(2u)
	/*Others*/
#define VA_TimeAnimation					(VA_Temp_ScrollIntervalInSec + SO_Temp_ScrollIntervalInSec)
#define SO_TimeAnimation					(2u)
	/**/
#define VA_DisplayBrightnessMode			(VA_TimeAnimation + SO_TimeAnimation)
#define SO_DisplayBrightnessMode			(2u)
	/**/
#define VA_DisplayBrightness				(VA_DisplayBrightnessMode + SO_DisplayBrightnessMode)
#define SO_DisplayBrightness				(2u)
	/**/
#define SizeOf_CharacterOnDisplay			(0x0006)
#define SizeOf_DisplayTextColumnArray		((SizeOf_CharacterOnDisplay * SO_Text_Message)+(2*NumberOf_DisplayColumn))
#define SizeOf_WhiteSpaces					(NumberOf_DisplayColumn/SizeOf_CharacterOnDisplay)
#define NumberOf_ColumnOfOneDisplay			(8)
#define NumberOf_Display					(12)
#define NumberOf_DisplayColumn				(NumberOf_Display * NumberOf_ColumnOfOneDisplay)
/**** END OF MACROS ******************************************************************************/

/**** TYPE DEFINITIONS ***************************************************************************/
enum
{
	SM_JustText = 0,
	SM_ScrollInAndOut
};

/*AppState_t*/
typedef enum
{
	AS_None = 0u,
	AS_Time,
	AS_Date,
	AS_Text,
	AS_Temp,
	AS_TextDone,
	AS_TextRunning
}AppState_t;
#define AppState_t uint8_t

/*AppState_t*/
typedef enum
{
	WiFi_None = 0,
	WiFi_NTP,
	WiFi_AP
}WiFiState_t;
#define WiFiState_t uint8_t

/*TextMode_t*/
typedef enum
{
	TM_MessageNoScroll = 0,
	TM_MessageScroll,
	TM_MessageScrollInAndOut
}TextMode_t;
#define TextMode_t uint16_t

/*DateMode_t*/
typedef enum
{
	DM_DateNoScroll = 0,
	DM_DateScrollInAndOut,
	DM_DateMessageScroll,
	DM_DateMessageScrollInAndOut
}DateMode_t;
#define DateMode_t uint16_t

typedef enum
{
	DB_Automatic = 0,
	DB_Manual
}DispBrightness_t;
#define DispBrightness_t uint16_t
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

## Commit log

2020-03-20 sorting files
    [Assem5.SLDASM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]
2020-03-20 reordering files
    [Assem5.SLDASM, FlipClockAssembly.SLDASM, MAX7219_8X8LED_BOARD.SLDPRT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]
2020-03-21 reordering sw project file structure
    [GPIOTEST Debug.cfg]
2020-03-22 Working SW with 96 column STM32L476RG nucleo Signed-off-by: foldvarid93 <foldvarid93@gmail.com>
2020-06-04 library alignment
    [CONTROL_BOARD.PrjPcb]
2020-08-08 ControlBoardV2 initial commit
    [CONTROL_BOARD_V2.PrjPcb, CONTROL_BOARD_V2.SchDoc]
2020-08-16 NodeMCU added to schematic
    [CONTROL_BOARD_V2.PrjPcb, CONTROL_BOARD_V2.SchDoc]
2020-08-17 Continue with schematic design
    [CONTROL_BOARD_V2.SchDoc, MAX7219_8X8LED_BOARD.PrjPcb]
2020-08-21 Pcb design first commit
    [CONTROL_BOARD_V2.PrjPcb, CONTROL_BOARD_V2.SchDoc, flipclock.DXF]
2020-08-22 Control board design finished
    [CONTROL_BOARD_V2.PrjPcb, CONTROL_BOARD_V2.SchDoc]
2020-08-23 PCB design done
    [CONTROL_BOARD_V2.PrjPcb, CONTROL_BOARD_V2.SchDoc]
2020-08-23 Fabrication Output files generated
    [CONTROL_BOARD_V2.SchDoc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]
2020-08-23 LED Matrix PCB redesign
    [MAX7219_8X8LED_BOARD.PcbDoc, MAX7219_8X8LED_BOARD.PrjPcb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]
2020-08-24 HW folder refactor
    [CONTROL_BOARD.PcbDoc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]
2020-09-06 RemoteXY develope
    [Assem5.SLDASM, FlipClockAssembly.SLDASM, MAX7219_8X8LED_BOARD.SLDPRT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]
2020-09-12 New truestudio sw project create
    [CONTROL_BOARD_V2.PrjPcb]
2020-09-14 RTC LSE in use Vbat RTC is working
    [CONTROL_BOARD_V2.PrjPcb]
2020-09-14 Interrupt priorities change
2020-09-20 SW folder reordering CUBEIDE project start
    [GPIOTEST Debug.cfg]
2020-09-27 NTPClient Arduino lib add
2020-09-30 date and time correct set
    [application.c, ntp.c]
2020-10-01 time animation bugfix round1
    [application.c, main.c]
2020-10-01 Scroll text bugfix and code clean
    [application.c, application.h]
2020-10-02 flip and scroll works well together timer3 adjusted
    [application.c]
2020-10-03 lasd display bugfix, chip select low only when load data to the matrix driver
    [application.c]
2020-10-05 display time with and without flip optionally
    [application.c, application.h, typedef.h]
2020-10-06 Working stage with 5 element of Remotexy
2020-10-08 EEPROM frame read and write
2020-10-08 text and date scroll fix
    [application.c, application.h, typedef.h]
2020-10-12 HTML respond error fix with interrupt priority
    [esp8266.c]
2020-10-14 folder structure change added text related app elements
    [GPIOTEST Debug.cfg]
2020-10-16 date time save rework
    [CONTROL_BOARD_V2.SchDoc]
2020-10-16 bugfix and new android app
    [application.c, eeprom.c, esp8266.c]
2020-10-23 TextData process function rework
    [application.c, application.h, esp8266.c]
2020-10-23 TMP100 temperature sensor add
2020-10-25 temperature added
2020-10-29 ntp automatic daylight saving
    [glass.dxf]
2020-10-30 modified spi send function
2020-11-02 lightsensor filter coefficient mod
2020-11-11 some mods
    [Glass.SLDDRW, glass.dxf]
2020-11-21 Temperature read ok
2023-03-21 fix "multiple definitions" errors
    [UartRingbuffer.c, application.c, application.h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]

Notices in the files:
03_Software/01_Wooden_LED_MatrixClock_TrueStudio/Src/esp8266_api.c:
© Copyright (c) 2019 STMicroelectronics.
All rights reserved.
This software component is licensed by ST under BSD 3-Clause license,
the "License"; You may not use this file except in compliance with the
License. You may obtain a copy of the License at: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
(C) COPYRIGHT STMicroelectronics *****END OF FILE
